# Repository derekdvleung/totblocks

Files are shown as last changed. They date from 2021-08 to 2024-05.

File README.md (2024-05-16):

# Introduction

TotBlocks are a series of 3D-printed mineral building blocks for constructing the crystal structures of biopyribole-palysepiole minerals.



[Website](https://derekdvleung.github.io/totblocks/)

[TotBlocks Video Abstract Video](https://doi.org/10.5446/57470)

[Assembly of TotBlocks Video](https://doi.org/10.5446/57471)

## How do I 3D print TotBlocks?

[3D Printing TotBlocks Video](https://doi.org/10.5446/57483)

The 3D models are available as \*.3mf (PrusaSlicer project files) and \*.stl files for 3D printing. 
Note that the \*.3mf files include the positions for support enforcers for *O* modules (`oblock`), 
whereas for \*.stl files the support enforcer (`stl/oblock/oblock-support-enforcer`) has to be added for the overhanging horizontal pegs of the *O* modules. 
When slicing (in PrusaSlicer), right click on the *O* module, then "add support enforcer".
It should be in the correct spot for single chain modules, but will need to be repositioned for other modules.
The support enforcer should be placed so that it covers the top widthwise pegs (these are overhangs, and thus need supports).

For more information on 3D printing TotBlocks, check out [TotBlocks on Printables](https://www.printables.com/model/177357-totblocks).

## Questions?

If you have any questions, start a thread in the [discussion](https://github.com/derekdvleung/totblocks/discussions)!

If you see any issues, please submit an [issue](https://github.com/derekdvleung/totblocks/issues).

# Repository contents

<!-- todo: add links -->

- [`3mf/`](3mf/)					All the \*.3mf (PrusaSlicer project files) can be found in this folder. See below (\*.stl folder contents) for descriptions of the respective \*.3mf files. Note that not all of the \*.stl files have a \*.3mf equivalent.
<!-- todo: add these files -->

- [`stl/`](stl/)					All the \*.stl files can be found in this folder.
  -	[`connectors/`](stl/connectors/)				Hexagonal pegs used to vertically connect *T*-*O*-*T* sheets for layered minerals.
	- [`brucite-connector.stl`](stl/connectors/brucite-connector.stl)			For brucite structure
	- [`chlorite-connector.stl`](stl/connectors/chlorite-connector.stl)			For chlorite structure
	- [`lizardite-connector.stl`](stl/connectors/lizardite-connector.stl)		For lizardite (kaolinite-serpentine group) structure
	- [`mica-connector.stl`](stl/connectors/mica-connector.stl)					For mica (2:1 phyllosilicate) structure
	
  - [`dual/`](stl/dual/) 							3D models used for the dual-colour version of TotBlocks (single chain, *w* = 1). 
													Each model has two parts, corresponding to two the different colours used in dual extrusion printing.
													These models should be overlain in the slicer for dual printing.
    - [`oblock-m2-plus-dual-0.stl`](stl/dual/oblock-m2-plus-dual-0.stl)			*O<sup>+</sup>* module, part 1.
    - [`oblock-m2-plus-dual-1.stl`](stl/dual/oblock-m2-plus-dual-1.stl)			*O<sup>+</sup>* module, part 2.
    - [`tblock-n1-minus-dual-0.stl`](stl/dual/oblock-n1-minus-dual-0.stl)		*T<sup>−</sup>* module, part 1.[^1]
    - [`tblock-n1-minus-dual-1.stl`](stl/dual/oblock-n1-minus-dual-1.stl)		*T<sup>−</sup>* module, part 2.[^1]
    - [`tblock-n1-plus-dual-0.stl`](stl/dual/oblock-m2-plus-dual-0.stl)			*T<sup>+</sup>* module, part 1.[^1]
    - [`tblock-n1-plus-dual-1.stl`](stl/dual/oblock-m2-plus-dual-1.stl)			*T<sup>+</sup>* module, part 2.[^1]
		
  - [`oblock/`](stl/oblock/)						*O* modules (`m` = *Z* from Nespolo and Bouznari, 2017)
    - [`oblock-m2-minus.stl`](stl/oblock/oblock-m2-minus.stl)					Single chain (*w* = 1) *O<sup>−</sup>* module.
    - [`oblock-m2-plus.stl`](stl/oblock/oblock-m2-plus.stl)						Single chain (*w* = 1) *O<sup>+</sup>* module.
    - [`oblock-m3-plus.stl`](stl/oblock/oblock-m3-plus.stl)						*Z*<sub>3</sub> *O<sup>+</sup>* module for kalifersite.
    - [`oblock-m5-minus.stl`](stl/oblock/oblock-m5-minus.stl)					Double chain (*w* = 2) *O<sup>−</sup>* module.
    - [`oblock-m5-plus.stl`](stl/oblock/oblock-m5-plus.stl)						Double chain (*w* = 2) *O<sup>+</sup>* module.
    - [`oblock-m6-plus.stl`](stl/oblock/oblock-m6-plus.stl)						*Z*<sub>6</sub> *O<sup>+</sup>* module for kalifersite.
    - [`oblock-m8-minus.stl`](stl/oblock/oblock-m8-minus.stl)					Triple chain (*w* = 3) *O<sup>−</sup>* module.
    - [`oblock-m8-plus.stl`](stl/oblock/oblock-m8-plus.stl)						Triple chain (*w* = 3) *O<sup>+</sup>* module.
    - [`oblock-m11-minus.stl`](stl/oblock/oblock-m11-minus.stl)					Quadruple chain (*w* = 4) *O<sup>−</sup>* module.
    - [`oblock-m11-plus.stl`](stl/oblock/oblock-m11-plus.stl)					Quadruple chain (*w* = 4) *O<sup>+</sup>* module.
    - [`oblock-support-enforcer.stl`](stl/oblock/oblock-support-enforcer.stl)	Support enforcer for the *O* modules. When slicing (in PrusaSlicer), right click on the *O* module, then "add support enforcer". 
																				It should be in the correct spot for single chain modules, but will need to be repositioned for other modules.
																				The support enforcer should be placed so that it covers the top widthwise pegs (these are overhangs, and thus need support).
    - [`single-octahedron-clips.stl`](stl/oblock/single-octahedron-clips.stl)	An octahedron that fits between *O* modules that are joined by phyllosilicate-type linkages to fill in the missing sites.
    - [`single-octahedron.stl`](stl/oblock/single-octahedron.stl)				An octahedron that fits between *O* modules that are joined by phyllosilicate-type linkages to fill in the missing sites.
																				This piece has additional clips that make it easier to hold on when the single octahedron is at the front or back of an *O* module.
	
  - [`quartz`](stl/quartz/)														Experimental modules for quartz. These modules do not have pags and thus have to be glued together to extend the structure.
    - [`quartz-module.stl`](stl/quartz/quartz-module.stl)						3<sub>2</sub> screw axis module for quartz (two repeats).

  - [`tblock`](stl/tblock/)							T modules (`n` = *w* from Leung and dePolo, 202x)
    - [`tblock-n1-minus.stl`](stl/tblock/tblock-n1-minus.stl)					Single chain (*w* = 1) *T<sup>−</sup>* module.[^1]
    - [`tblock-n1-plus.stl`](stl/tblock/tblock-n1-plus.stl)						Single chain (*w* = 1) *T<sup>+</sup>* module.[^1]
    - [`tblock-n2-minus.stl`](stl/tblock/tblock-n2-minus.stl)					Double chain (*w* = 2) *T<sup>−</sup>* module.[^1]
    - [`tblock-n2-plus.stl`](stl/tblock/tblock-n2-plus.stl)						Double chain (*w* = 2) *T<sup>+</sup>* module.[^1]
    - [`tblock-n3-minus.stl`](stl/tblock/tblock-n3-minus.stl)					Triple chain (*w* = 3) *T<sup>−</sup>* module.[^1]
    - [`tblock-n3-plus.stl`](stl/tblock/tblock-n3-plus.stl)						Triple chain (*w* = 3) *T<sup>+</sup>* module.[^1]
    - [`tblock-n4-minus.stl`](stl/tblock/tblock-n4-minus.stl)					Quadruple chain (*w* = 4) *T<sup>−</sup>* module.[^1] 
    - [`tblock-n4-plus.stl`](stl/tblock/tblock-n4-plus.stl)						Quadruple chain (*w* = 4) *T<sup>+</sup>* module.[^1]

- [`LICENSE`](LICENSE) 				The copyright license (GPLv3) for the TotBlocks project.
- [`totblocks.scad`](totblocks.scad)										The source code to generate TotBlocks. See below for method documentation for `totblocks.scad`.

[^1]: Note that the *T<sup>+</sup>* and *T<sup>−</sup>* notation is used here to differentiate between the two types of T modules. 
 However, the *T<sup>+</sup>* and *T<sup>−</sup>* notation actually corresponds to the orientation of the *T* modules (apices pointing up = <sup>+</sup>, down = <sup>−</sup>) rather than the modules themselves.

# Bill of materials

## Starter set (can be used to build most of the structures)

- 4× oblock-m2-plus
- 4× tblock-n1-plus
- 4× tblock-n1-minus
- 4× oblock-m5-plus
- 4× tblock-n2-plus
- 4× tblock-n2-minus
- 4× single-octahedron
- 4× single-octahedron-clips
- 2× mica-connector (or the other connectors, depending on if the others should be printed. Note: the mica connectors can be substituted for 2 cm diameter marbles or 3D-printed spheres. These represent the interlayer cations in the mica structure.)

Additional blocks beyond the starter set are needed to build the orthopyroxene, protopyroxene, [clinojimthompsonite,] chesterite, sepiolite, and kalifersite structures.

## Mica group (2:1 phyllosilicates)

- 4× oblock-m5-plus
- 4× tblock-n2-plus
- 4× tblock-n2-minus
- 2× single-octahedron
- 2× single-octahedron-clips
- 2× mica-connector (Note: the mica connectors can be substituted for 2 cm diameter marbles or 3D-printed spheres. These represent the interlayer cations in the mica structure.)

[2:1 Phyllosilicates Video](https://doi.org/10.5446/57470)

## Pyroxene group

[Pyroxene Group Video](https://doi.org/10.5446/57473)

### Clinopyroxene

- 4× oblock-m2-plus
- 4× tblock-n1-plus
- 4× tblock-n1-minus

[Pyroxene Group Video](https://doi.org/10.5446/57473)

### Orthopyroxene

- 4× oblock-m5-plus
- 4× oblock-m5-minus
- 8× tblock-n2-plus
- 8× tblock-n2-minus

[Pyroxene Group Video](https://doi.org/10.5446/57473)

### Protopyroxene

- 4× oblock-m5-plus
- 4× oblock-m5-minus
- 8× tblock-n2-plus
- 8× tblock-n2-minus

[Pyroxene Group Video](https://doi.org/10.5446/57473)

## Amphibole supergroup

- 4× oblock-m5-plus
- 4× tblock-n2-plus
- 4× tblock-n2-minus

[Amphibole Supergroup Video](https://doi.org/10.5446/57474)

## Clinojimthompsonite

- 4× oblock-m8-plus
- 4× tblock-n3-plus
- 4× tblock-n3-minus

[Clinojimthompsonite and Chesterite Video](https://doi.org/10.5446/57475)

## Chesterite

- 2× oblock-m5-plus
- 2× oblock-m5-minus
- 4× tblock-n2-plus
- 4× tblock-n2-minus
- 2× oblock-m8-plus
- 2× oblock-m8-minus
- 4× tblock-n3-plus
- 4× tblock-n3-minus

[Clinojimthompsonite and Chesterite Video](https://doi.org/10.5446/57475)

## Palygorskite group

- 4× oblock-m5-plus
- 4× tblock-n2-plus
- 4× tblock-n2-minus

[Palygorskite Group](https://doi.org/10.5446/57476)

## Sepiolite group

- 2× oblock-m8-plus
- 2× oblock-m8-minus
- 4× tblock-n3-plus
- 4× tblock-n3-minus

[Sepiolite Group](https://doi.org/10.5446/57477)

## Kalifersite

- 4× oblock-m3-plus
- 4× tblock-n2-plus
- 4× tblock-n2-minus
- 4× oblock-m6-plus
- 4× tblock-n3-plus
- 4× tblock-n3-minus

[Kalifersite Video](https://doi.org/10.5446/57479)

## Brucite group

- 4× oblock-m5-plus
- 2× single-octahedron
- 2× single-octahedron-clips
- 4× brucite-connector

[Brucite Group Video](https://doi.org/10.5446/57480)

## Lizardite (kaolinite-serpentine group)

- 4× oblock-m5-plus
- 4× tblock-n2-plus
- 2× single-octahedron
- 2× single-octahedron-clips
- 4× lizardite-connector

[Kaolinite-Serpentine Group Video](https://doi.org/10.5446/57481)

## Chlorite group

- 4× oblock-m5-plus
- 2× oblock-m5-minus
- 4× tblock-n2-plus
- 4× tblock-n2-minus
- 3× single-octahedron
- 3× single-octahedron-clips
- 4× chlorite-connector

[Chlorite Group](https://doi.org/10.5446/57482)

# Method documentation

## Hard-coded parameters
<!-- todo: flush this out -->
These parameters are hard-coded into the TotBlocks file, but they can be adjusted using the built-in Customizer in OpenSCAD.

### Module size parameters
`t` = the true side length of the tetrahedra in the *T* modules (default 10 mm). This will define the size of both the *T* and *O* modules, since both are geometrically related.  
`numBlocks` = periodic length of the blocks (*l* in Leung and dePolo, 202x). Note that the code currently does not support half lengths.

### Peg size parameters
`pegRadius` = radius of the horizontal and vertical pegs (default 1.8 mm).  
`pegZLength` = length of vertical pegs (Z direction) (default 2.4 mm).  
`pegYLength` = length of lengthwise pegs (Y direction) (default 5 mm).  
`pegXLength` = length of widthwise pegs (X direction) (default 5 mm).  
`pegZLowerLength` = length that the vertical pegs (Z direction) should extend (default 4.4 mm).  
`pegZRotate` = orientation of the vertical pegs (Z direction) (default 90 degrees).  
`oAdjustHexHeight` = height of the hexagonal slots (Z direction) in the O modules (default 2.6 mm).  
`tMinusCutoff` = Offset used to determine where the widthwise side of the *T* modules are cut off (default 0 mm).  
`tetBridgeHeight` = Offset used for the height of the rectangular bridges that connect the tetrahedra in the *T* modules (default 0 mm).  

### Tolerance parameters
`toleranceZ` = tolerance for the radius of the vertical pegs (Z direction) (default 0 mm).  
`tZMinusTolerance` = (deprecated) tolerance for slots in *T<sup>−</sup>* modules (slots were replaced by pegs in a newer iteration) (default 0 mm).  
`lengthTolerance` = tolerance for lengths of vertical pegs (Z direction) (default 0.2 mm).  
`SlotXHeightTolerance` = extends the height (Z direction) for the widthwise pegs (X direction) to reduce issues from sagging due to bridging (default 0.6 mm).  
`toleranceXY` = tolerance for the radius of the lengthwise and widthwise pegs (Y and X directions, respectively) (default 0 mm).  

## Constants
These values are used for internal reference (don't change them).  
`PLUS = 1` constant used to denote positive orientation.  
`MINUS = 0` constant used to denote negative orientation.  

`T_SINGLE_CHAIN = 1` constant for single-chain-width *T* modules.  
`T_DOUBLE_CHAIN = 2` constant for double-chain-width *T* modules.  
`T_TRIPLE_CHAIN = 3` constant for triple-chain-width *T* modules.  

`O_SINGLE_CHAIN = 2` constant for single-chain-width *O* modules.  
`O_DOUBLE_CHAIN = 5` constant for double-chain-width *O* modules.  
`O_TRIPLE_CHAIN = 8` constant for triple-chain-width *O* modules.  

## TotBlocks modules

	tBlock (n = 1, apex = PLUS);

Produces a *T* module of certain width and polarity.

`n` = width of module (`T_SINGLE_CHAIN` = 1, `T_DOUBLE_CHAIN` = 2, `T_TRIPLE_CHAIN` = 3)  
`apex` = direction that the tetrahedra point (`PLUS` or `MINUS`)[^1]

***

	oBlock (m = 2, apex = PLUS);

Produces an *O* module of certain width and polarity

`m` = number of *M* sites in the module (`O_SINGLE_CHAIN` = 2, `O_DOUBLE_CHAIN` = 5, `O_TRIPLE_CHAIN` = 8)  
`apex` = direction that the octahedra point (`PLUS` or `MINUS`)

***

	oBlockKalifersite (m = 3, apex = PLUS);

A temporary method for producing O modules for kalifersite, which have the width-wise pegs removed. It is anticipated that this method will be deprecated and added to the `oBlock` method.
 
`m` = number of *M* sites in the module (3 = *Z*<sub>3</sub> module (double chain), 6 = *Z*<sub>6</sub> module (triple chain))  
`apex` = direction that the octahedra point (`PLUS` or `MINUS`)

## Single octahedron pieces

	oBlockOne (apex = PLUS, pegs = true);

Produces a single octahedron piece. Note that there is no difference between PLUS and MINUS versions.

`apex` = direction that the octahedra point (`PLUS` or `MINUS`)  
`pegs` = if `TRUE`, includes clips for the octahedra; if `FALSE`, does not include clips

## Peg connectors

	micaPeg ();

Produces a vertical peg for the mica-group minerals.

***

	chloriteBrucitePeg (length);

Produces a vertical peg for the chlorite and brucite groups, as well as lizardite (kaolinite-serpentine group)

`length` = length of peg (chlorite = `CHLORITE_HEIGHT`, brucite = `BRUCITE_HEIGHT`, lizardite = `LIZARDITE_HEIGHT`)

## Dual prints

	oBlockDual (apex = PLUS, dual = 0);

Produces two parts of a dual print for single-chain-width *O* modules.

`apex` = direction that the octahedra point (`PLUS` or `MINUS`)  
`dual` = part number (`0` or `1`)

***

	tBlockDual2 (n = 1, apex = PLUS, dual = 0);

Produces two parts of a dual print for *T* modules.

`n` = width of module (`1` = single chain, `2` = double chain, `3` = triple chain)  
`apex` = direction that the tetrahedra point (`PLUS` or `MINUS`)[^1]  
`dual` = part number (`0` or `1`)  

## Quartz

	quartzModule ();

Produces a quartz module.

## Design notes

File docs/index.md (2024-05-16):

Table of contents
* TOC
{:toc}

<!-- This is a test landing page for TotBlocks. -->

<!-- TODO: add paper link, youtube resources, printables -->

# Introduction

<iframe width="560" height="315" src="https://www.youtube.com/embed/pNsD5MDUdqU" title="YouTube video player" frameborder="0" allow="accelerometer; autoplay; clipboard-write; encrypted-media; gyroscope; picture-in-picture; web-share" allowfullscreen></iframe>

TotBlocks are a series of 3D-printed mineral building blocks for constructing the crystal structures of modular rock-forming minerals, including minerals of the biotite-pyroxene-amphibole (biopyribole) and palygorskite-sepiolite (palysepiole) series, as well as layered minerals of the brucite, kaolinite-serpentine, and chlorite groups. To learn more about TotBlocks, check out the video above and the papers on the design and theory of TotBlocks, as well as a case study of using TotBlocks in an undergradute mineralogy lab session.

## Useful publications and links

- **TotBlocks design and theory paper:** [Leung, D.D.V. and dePolo, P.E. (2022) TotBlocks: exploring the relationships between modular rock-forming minerals with 3D-printed interlocking brick modules. _European Journal of Mineralogy_, 34, 523-538, https://doi.org/10.5194/ejm-34-523-2022.](https://ejm.copernicus.org/articles/34/523/2022/)

- **TotBlocks pedagogical case study:** [Leung, D.D.V. and dePolo, P.E. (2023) GC Insights: The crystal structures behind the optical properties of minerals - a case study of using TotBlocks in an undergraduate mineralogy lab. _Geoscience Communcation_, preprint on EGUsphere, https://doi.org/10.5194/egusphere-2023-294.](https://egusphere.copernicus.org/preprints/2023/egusphere-2023-294/)

- **TotBlocks mirrored repository on Zenodo:** [Leung, D.D.V. (2022) derekdvleung/totblocks: TotBlocks 2022.05 (totblocks-2022.05), Zenodo [code], https://doi.org/10.5281/zenodo.5240816.](https://zenodo.org/badge/latestdoi/398404495) 
<!-- [![DOI](https://zenodo.org/badge/398404495.svg)](https://zenodo.org/badge/latestdoi/398404495)-->

- **TotBlocks YouTube playlist:** [https://youtube.com/playlist?list=PLn1WI6cV9CAvNvtO0wXdM_Uy9zV6C942s](https://youtube.com/playlist?list=PLn1WI6cV9CAvNvtO0wXdM_Uy9zV6C942s)

- **TotBlocks on GitHub:** [https://github.com/derekdvleung/totblocks](https://github.com/derekdvleung/totblocks)
  -	If you have any questions, please start a thread in the [discussion here](https://github.com/derekdvleung/totblocks/discussions).
If you see any issues, please submit an [issue here](https://github.com/derekdvleung/totblocks/issues).

# How do I 3D print TotBlocks?

<iframe width="560" height="315" src="https://www.youtube.com/embed/GAaxp7R7IAs" title="YouTube video player" frameborder="0" allow="accelerometer; autoplay; clipboard-write; encrypted-media; gyroscope; picture-in-picture; web-share" allowfullscreen></iframe>

To 3D print TotBlocks, check out the video above. The 3D models for TotBlocks can be found on [Printables here](https://www.printables.com/model/177357-totblocks). The 3D models are available as \*.3mf (PrusaSlicer project files) and \*.stl files for 3D printing. 
Note that the \*.3mf files include the positions for support enforcers for *O* modules (`oblock`) to be used with PrusaSlicer, 
whereas for \*.stl files the support enforcer (`stl/oblock/oblock-support-enforcer`) has to be added for the overhanging horizontal pegs of the *O* modules. 
When slicing (in PrusaSlicer), right click on the *O* module, then "add support enforcer".
It should be in the correct spot for single chain modules, but will need to be repositioned for other modules.
The support enforcer should be placed so that it covers the top widthwise pegs (these are overhangs, and thus need supports).

## Supported 3D printers

TotBlocks has been tested on the following 3D printers:
- Prusa i3 MK3S (original design for TotBlocks)
- Creality Ender 5 (Laurentian University)
- Creality Ender 3 (thanks to Phillip Barak for testing) 
- Ultimaker S5 (some issues with peg and slot tolerances)
- MakerBot Sketch Large (thanks to Loretta Dickson for testing)
- Entina (thanks to Loretta Dickson for testing)

# Building the crystal structures

<iframe width="560" height="315" src="https://www.youtube.com/embed/JqNwlT4ukXY" title="YouTube video player" frameborder="0" allow="accelerometer; autoplay; clipboard-write; encrypted-media; gyroscope; picture-in-picture; web-share" allowfullscreen></iframe>

## Mica group (2:1 phyllosilicates)

<iframe width="560" height="315" src="https://www.youtube.com/embed/B0o2lecr-tU" title="YouTube video player" frameborder="0" allow="accelerometer; autoplay; clipboard-write; encrypted-media; gyroscope; picture-in-picture; web-share" allowfullscreen></iframe>

Watch the video above to learn more about the 2:1 phyllosilicates, and construct the crystal structure of the mica group using TotBlocks.

Parts needed:
- 4× oblock-m5-plus
- 4× tblock-n2-plus
- 4× tblock-n2-minus
- 2× single-octahedron
- 2× single-octahedron-clips
- 2× mica-connector (Note: the mica connectors can be substituted for 2 cm diameter marbles or 3D-printed spheres. These represent the interlayer cations in the mica structure.)

## Pyroxene group

<iframe width="560" height="315" src="https://www.youtube.com/embed/7puU0kn26aU" title="YouTube video player" frameborder="0" allow="accelerometer; autoplay; clipboard-write; encrypted-media; gyroscope; picture-in-picture; web-share" allowfullscreen></iframe>

Watch the video above to learn more about the pyroxenes and their three structural varieties ('polytypes')

### Clinopyroxene

Parts needed:
- 4× oblock-m2-plus
- 4× tblock-n1-plus
- 4× tblock-n1-minus

### Orthopyroxene

Parts needed:
- 4× oblock-m5-plus
- 4× oblock-m5-minus
- 8× tblock-n2-plus
- 8× tblock-n2-minus

### Protopyroxene

Parts needed:
- 4× oblock-m5-plus
- 4× oblock-m5-minus
- 8× tblock-n2-plus
- 8× tblock-n2-minus

## Amphibole supergroup

<iframe width="560" height="315" src="https://www.youtube.com/embed/ZTIgtaDmqug" title="YouTube video player" frameborder="0" allow="accelerometer; autoplay; clipboard-write; encrypted-media; gyroscope; picture-in-picture; web-share" allowfullscreen></iframe>

Parts needed:
- 4× oblock-m5-plus
- 4× tblock-n2-plus
- 4× tblock-n2-minus

## Clinojimthompsonite

<iframe width="560" height="315" src="https://www.youtube.com/embed/aJ-CMEkaL5I" title="YouTube video player" frameborder="0" allow="accelerometer; autoplay; clipboard-write; encrypted-media; gyroscope; picture-in-picture; web-share" allowfullscreen></iframe>

Parts needed:
- 4× oblock-m8-plus
- 4× tblock-n3-plus
- 4× tblock-n3-minus

## Chesterite

<iframe width="560" height="315" src="https://www.youtube.com/embed/aJ-CMEkaL5I" title="YouTube video player" frameborder="0" allow="accelerometer; autoplay; clipboard-write; encrypted-media; gyroscope; picture-in-picture; web-share" allowfullscreen></iframe>

Parts needed:
- 2× oblock-m5-plus
- 2× oblock-m5-minus
- 4× tblock-n2-plus
- 4× tblock-n2-minus
- 2× oblock-m8-plus
- 2× oblock-m8-minus
- 4× tblock-n3-plus
- 4× tblock-n3-minus

## Palygorskite group

<iframe width="560" height="315" src="https://www.youtube.com/embed/_oIfYW3Yn7k" title="YouTube video player" frameborder="0" allow="accelerometer; autoplay; clipboard-write; encrypted-media; gyroscope; picture-in-picture; web-share" allowfullscreen></iframe>

Parts needed:
- 4× oblock-m5-plus
- 4× tblock-n2-plus
- 4× tblock-n2-minus

## Sepiolite group

<iframe width="560" height="315" src="https://www.youtube.com/embed/Y6VKkh_y93w" title="YouTube video player" frameborder="0" allow="accelerometer; autoplay; clipboard-write; encrypted-media; gyroscope; picture-in-picture; web-share" allowfullscreen></iframe>

Parts needed:
- 2× oblock-m8-plus
- 2× oblock-m8-minus
- 4× tblock-n3-plus
- 4× tblock-n3-minus

## Kalifersite

<iframe width="560" height="315" src="https://www.youtube.com/embed/xG3E6Dk2YI0" title="YouTube video player" frameborder="0" allow="accelerometer; autoplay; clipboard-write; encrypted-media; gyroscope; picture-in-picture; web-share" allowfullscreen></iframe>

Parts needed:
- 4× oblock-m3-plus
- 4× tblock-n2-plus
- 4× tblock-n2-minus
- 4× oblock-m6-plus
- 4× tblock-n3-plus
- 4× tblock-n3-minus

## Brucite group

<iframe width="560" height="315" src="https://www.youtube.com/embed/X81bQ844Kgs" title="YouTube video player" frameborder="0" allow="accelerometer; autoplay; clipboard-write; encrypted-media; gyroscope; picture-in-picture; web-share" allowfullscreen></iframe>

Parts needed:
- 4× oblock-m5-plus
- 2× single-octahedron
- 2× single-octahedron-clips
- 4× brucite-connector

## Lizardite (kaolinite-serpentine group)

<iframe width="560" height="315" src="https://www.youtube.com/embed/_taepX3pt5U" title="YouTube video player" frameborder="0" allow="accelerometer; autoplay; clipboard-write; encrypted-media; gyroscope; picture-in-picture; web-share" allowfullscreen></iframe>

Parts needed:
- 4× oblock-m5-plus
- 4× tblock-n2-plus
- 2× single-octahedron
- 2× single-octahedron-clips
- 4× lizardite-connector

## Chlorite group

<iframe width="560" height="315" src="https://www.youtube.com/embed/0-9Vbss5MxI" title="YouTube video player" frameborder="0" allow="accelerometer; autoplay; clipboard-write; encrypted-media; gyroscope; picture-in-picture; web-share" allowfullscreen></iframe>

Parts needed:
- 4× oblock-m5-plus
- 2× oblock-m5-minus
- 4× tblock-n2-plus
- 4× tblock-n2-minus
- 3× single-octahedron
- 3× single-octahedron-clips
- 4× chlorite-connector

# Contact

To contact Derek D.V. Leung, check out [the contact form on his website here](https://derekdvleung.wixsite.com/main/contact).

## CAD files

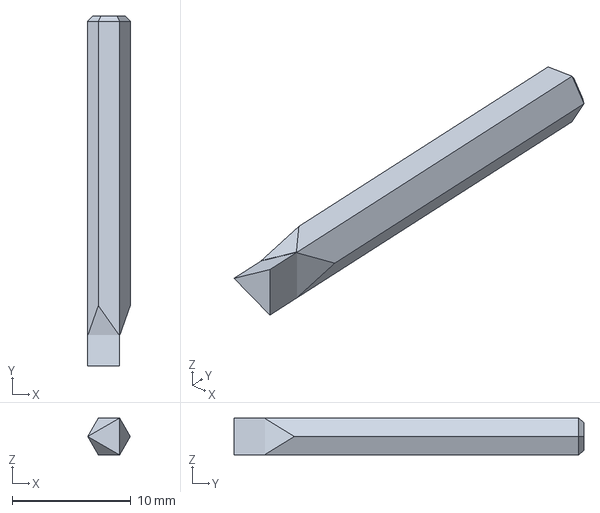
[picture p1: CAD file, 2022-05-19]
3mf/connectors/lizardite-connector.3mf
3.60 x 29.5 x 3.12 mm

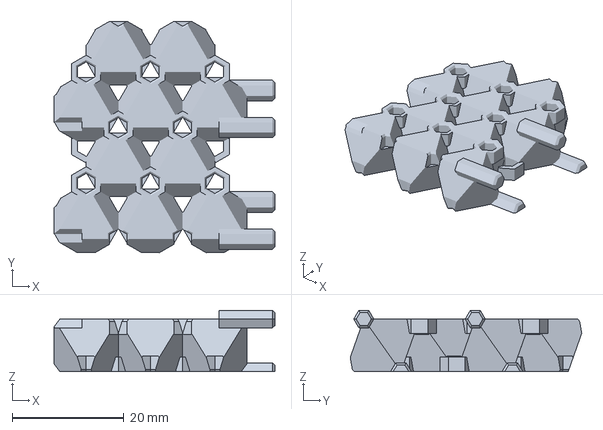
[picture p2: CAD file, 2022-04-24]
3mf/oblock/oblock-m5-minus.3mf
39.6 x 41.5 x 11.0 mm

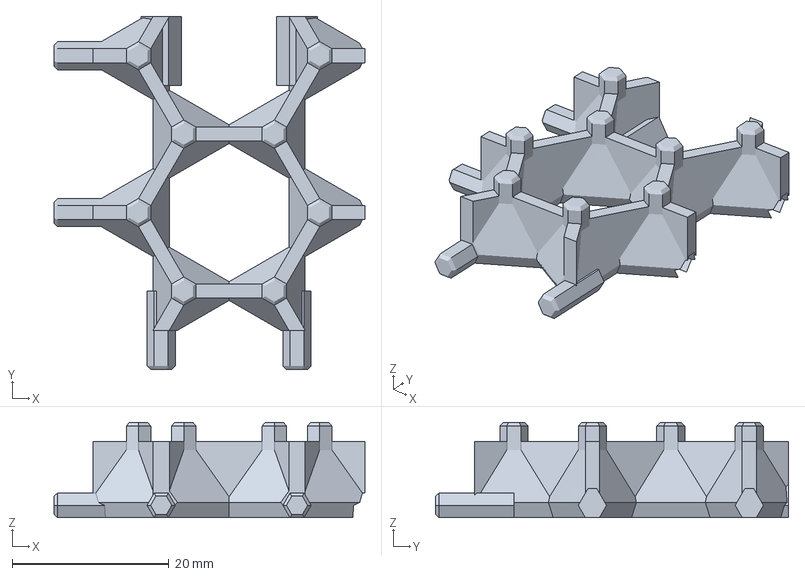
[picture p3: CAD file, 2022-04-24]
3mf/tblock/tblock-n2-minus.3mf
39.6 x 45.0 x 12.1 mm

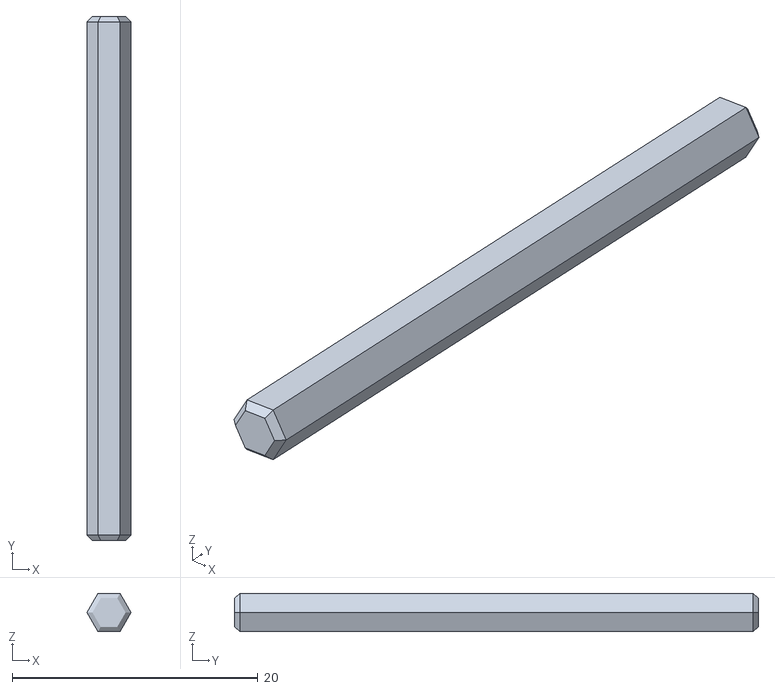
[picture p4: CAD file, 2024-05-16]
stl/connectors/smectite-connector.stl
3.60 x 42.6 x 3.12

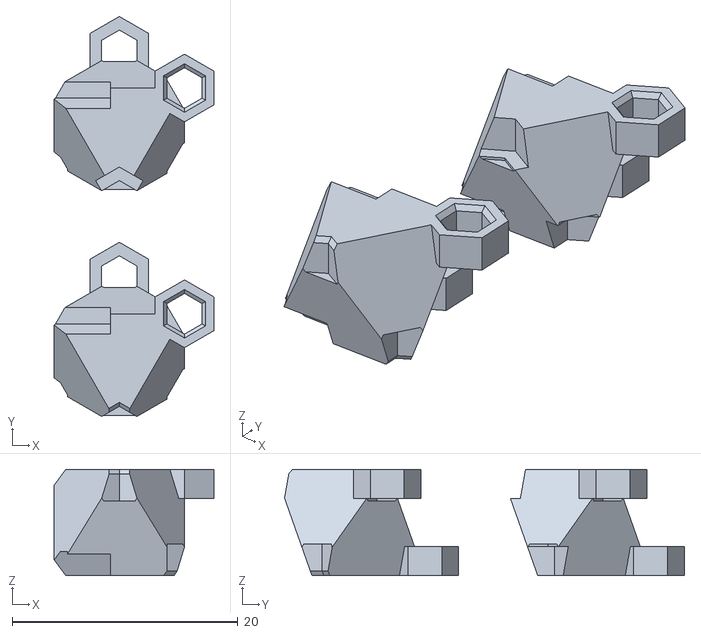
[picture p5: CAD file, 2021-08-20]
stl/dual/oblock-m2-plus-dual-0.stl
14.1 x 35.4 x 9.43

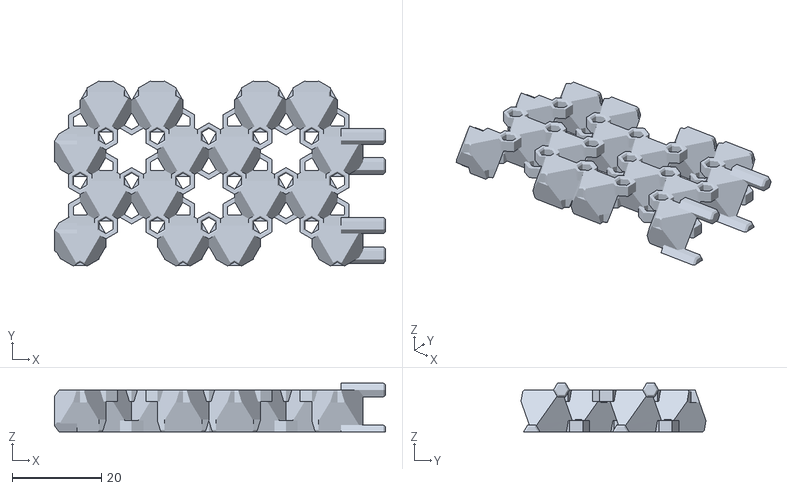
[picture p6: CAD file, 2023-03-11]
stl/oblock/dioctahedral/oblock-dioctahedral-m11-plus.stl
74.3 x 41.5 x 11.0

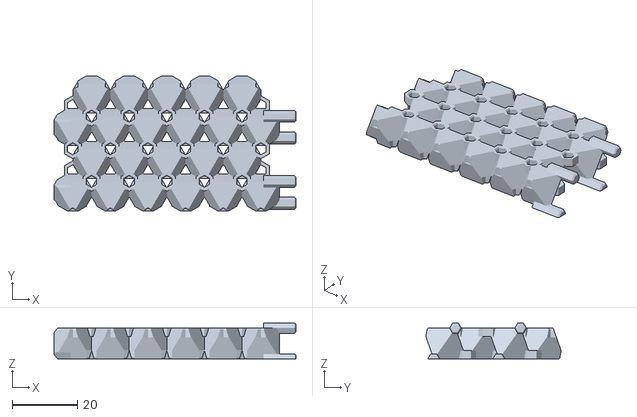
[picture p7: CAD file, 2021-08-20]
stl/oblock/oblock-m11-plus.stl
74.3 x 41.5 x 11.0

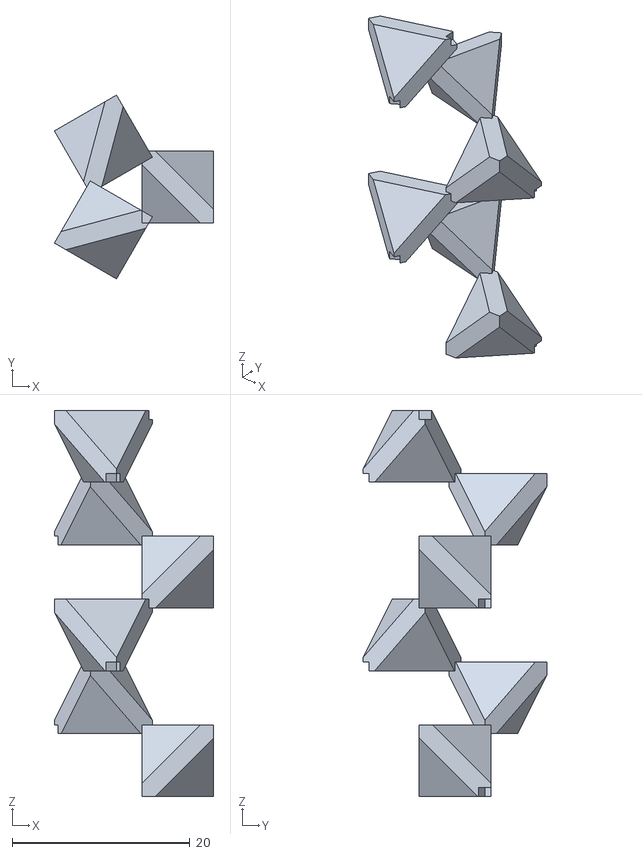
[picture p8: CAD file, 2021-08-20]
stl/quartz/quartz-module.stl
17.9 x 20.7 x 43.4

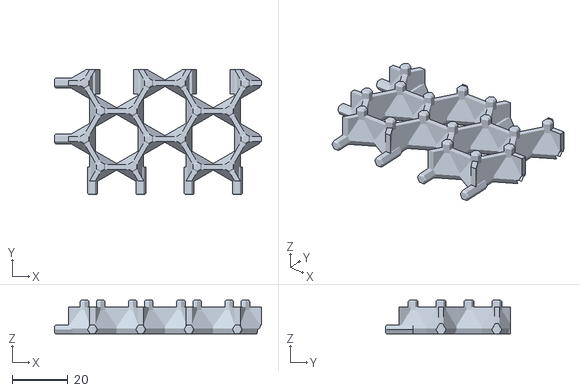
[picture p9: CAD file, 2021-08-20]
stl/tblock/tblock-n4-minus.stl
74.3 x 45.0 x 12.1

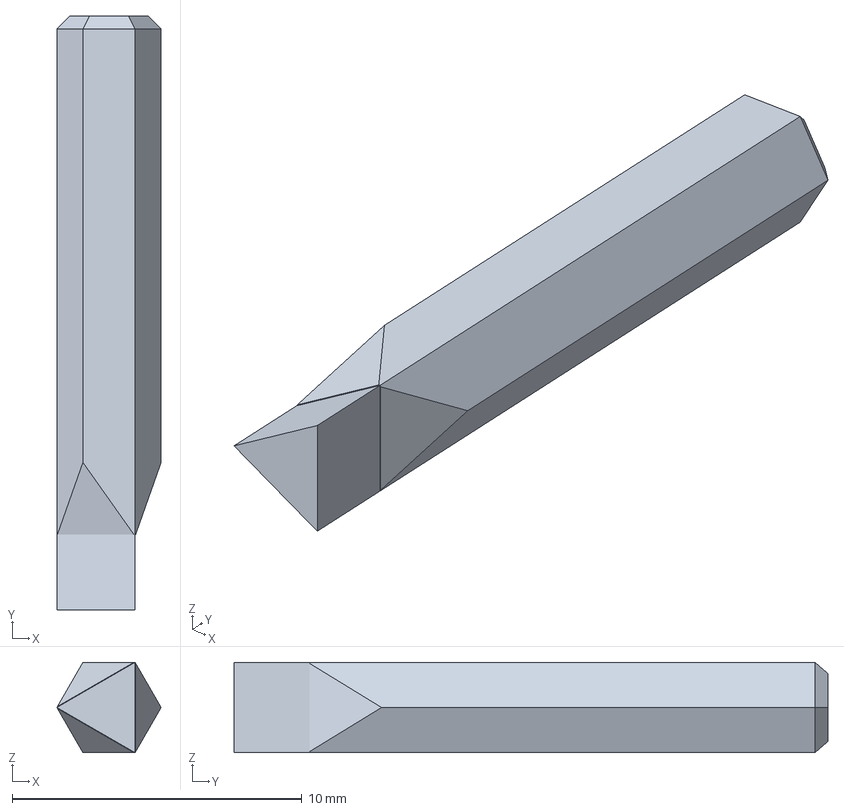
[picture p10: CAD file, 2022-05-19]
3mf/connectors/brucite-connector.3mf
3.60 x 20.5 x 3.12 mm

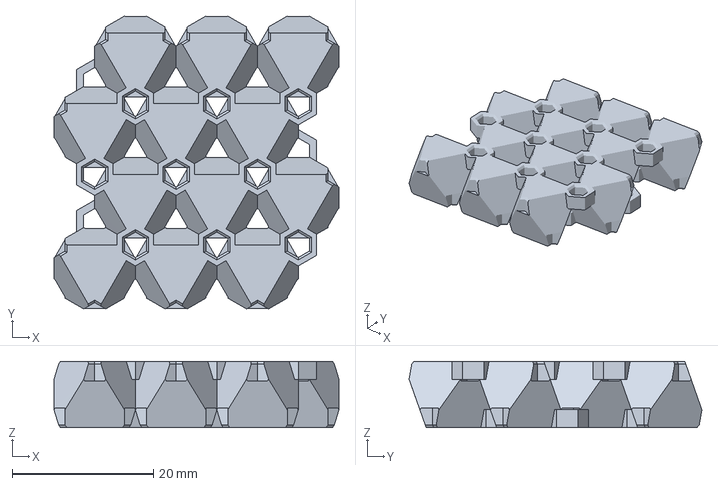
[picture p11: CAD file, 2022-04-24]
3mf/oblock/oblock-m6-plus.3mf
40.4 x 41.5 x 9.43 mm

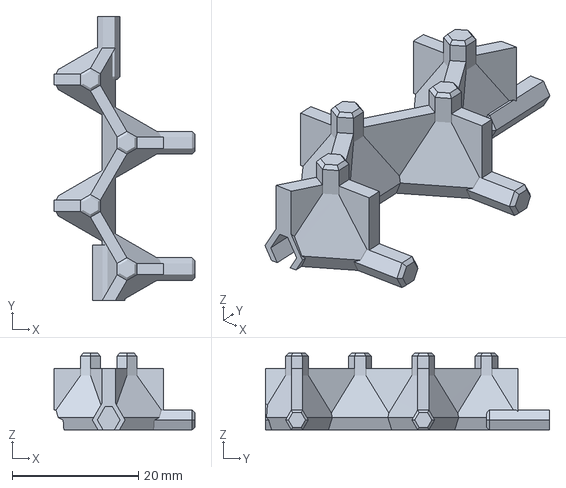
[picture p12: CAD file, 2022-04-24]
3mf/tblock/tblock-n1-plus.3mf
22.3 x 45.0 x 12.1 mm

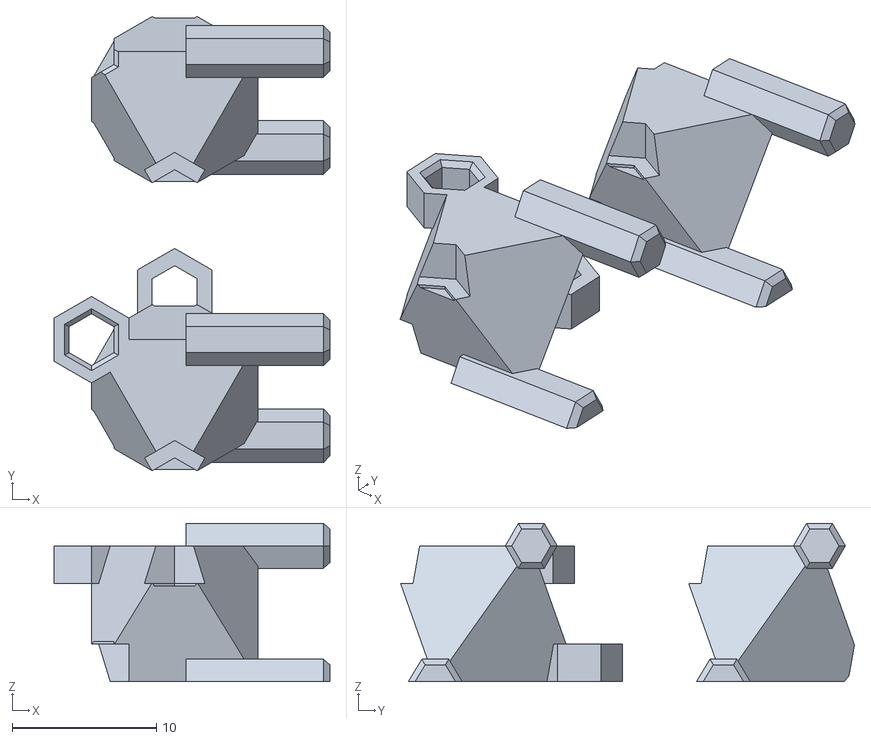
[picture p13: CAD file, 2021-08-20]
stl/dual/oblock-m2-plus-dual-1.stl
19.1 x 31.5 x 11.0

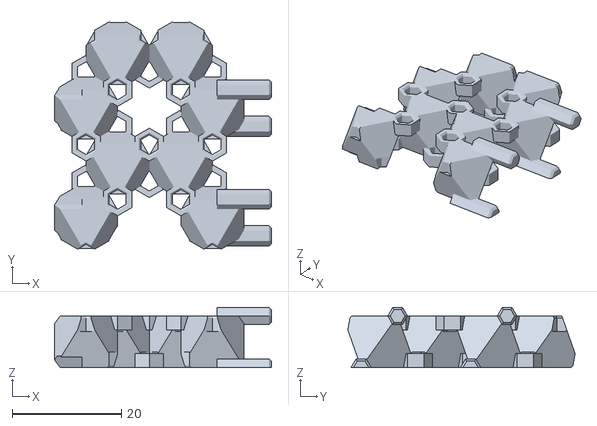
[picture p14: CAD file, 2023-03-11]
stl/oblock/dioctahedral/oblock-dioctahedral-m5-plus.stl
39.6 x 41.5 x 11.0

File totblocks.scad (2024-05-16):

/* Copyright (C) 2021 Derek Leung <dleung@laurentian.ca>
    This program is free software: you can redistribute it and/or modify it under the terms of the GNU General Public License version 3 as published by the Free Software Foundation. This program is distributed in the hope that it will be useful, but WITHOUT ANY WARRANTY; without even the implied warranty of MERCHANTABILITY or FITNESS FOR A PARTICULAR PURPOSE.  See the GNU General Public License for more details. You should have received a copy of the GNU General Public License along with this program.  If not, see <https://www.gnu.org/licenses/>.
*/

/*TODO:
-put peg holes into T modules so that M2, M4, A, and I sites can be inserted into the structure
-convert modules to include variable length parameters
-convert O module so that half lengths are possible*/

/*********************************************************************************************************

                            PARAMETERS

**********************************************************************************************************/

/* [Module size parameters] */
//Length of the blocks (l) N.B. currently does not support half lengths
numBlocks = 2; 
// Tetrahedron side length (mm)
t = 10;//10;  // tetrahedron side length
a = t/2; // tetrahedron half side length
ts = sqrt(3)/2*t; // slant height of tetrahedron
tx = t/sqrt(12); //length of line segment from base of triangle to centroid of triangle
th = sqrt(6)/3*t; // true height of tetrahedron
tCR = sqrt(6)/4*t; //circumradius of tetrahedron

factor = tCR/1.62; //the scale of the structure, assuming a Si-O bond distance of 1.62 A (Smith and Bailey, 1963)

//echo(oh);
echo ("factor:" , factor);
echo (factor*3.2/2);
echo (tCR);
echo (th/factor); // real height of tetrahedron in A
echo (oh/factor); // real height of octahedron in A

o = 2*(ts-tx);
b = o/2;
os = sqrt(3)/2*o; // slant height of octahedron face
ox = os/3;
oa = 4*ox; //apex-to-apex length of octahedron (flat)
oh = sqrt(o*o-(2*ox*2*ox)); //true height of flat-lying octahedron
oCR = o*sqrt(1/2); // double-checked bond distance of O sites

//These minerals use vertical pegs to connect the O-O underside bonds, i.e., chloriteBrucitePeg module
MICA_HEIGHT = 3.2*factor + 2*th; // based on Hendricks and Jefferson (1939)
CHLORITE_HEIGHT = 7.01*factor; // based on Zanazzi et al. (2007)
BRUCITE_HEIGHT = 4.73*factor; // based on Nagai et al. (2000)
LIZARDITE_HEIGHT =7.23*factor; // based on Mellini (1982)
SMECTITE_HEIGHT = 15*factor - oh; // this is the true vertical distance based on Viani et al (2002)
                //12.98*factor; // this value is the slant height of the pegs, including offset, based on Viani et al. (2002)


echo (oCR/factor); // bond distance of O sites

echo (2*ts/(oh+2*th)); // ratio of width to height of modules

echo ((th+oh)/(oh+2*th)); // vertical offset for pyribole-type linkages

/* [Peg size parameters] */
//Radius of the horizontal (lengthwise and widthwise) and vertical pegs
pegRadius = 1.8;//1; 

//Length of vertical pegs
pegZLength = 2.4;////oh/2; 

//Length of lengthwise pegs
pegYLength = 5;//b;//b; 

//Length of widthwise pegs
pegXLength = 5;//b;

//Extends the opposite end of the vertical pegs on the Z axis (mm)
pegZLowerLength = 4.4;//2.4;// 4.4; 

//Orientation of the vertical pegs
pegZRotate =90;//0

//Determines the height of the hexagonal slots in the O modules
oAdjustHexHeight =2.6;//oh/2-pegZLength ;// 2.2;

//Offset used to determine where the widthwise side of the T modules are cut off
tMinusCutoff = 0;

//Offset for the height of the rectangular bridges that connect the tetrahedra in the T modules
tetBridgeHeight = 0;//2.66-0.8; //2.66 to get flush edges




extraBlocks = numBlocks-1; //number of blocks, not including base block

/* [Tolerance parameters] */

echo(b);
//Tolerance for Z peg radius
toleranceZ = 0; 

//Tolerance for Z peg length
lengthTolerance =0.2; 

//Extends widthwise and lengthwise slots for a specified Z height to reduce sagging from bridging
slotXHeightTolerance =0.6;

// Vertical offset used for adding thickness to pegs
toleranceXY = 0;
tOffset = sqrt(3)/2*pegRadius; 
//tExpand = 0;//5;//3;
//tExpandHeight = 0;//th+tOffset;

/* [Deprecated] */
// Colors for simpTOT module, that shows idealized T and O modules - only works in Preview Mode
tColor = "crimson";
oColor = "yellowgreen";
oMColor = "yellow";

bottomDesignHeight = 0.4;

tZMinusTolerance = 0;

//Increases the size of the tetrahedra in the T modules of a previous iteration of TotBlocks
tBaseScale = 1;//1.4; //1.2


// This module prevents internal constants from being customized.
module customizerLimit (){}

// CONSTANTS
PLUS = 0; // constants used to define the direction of the modules
MINUS = 1; // constants used to define the direction of the modules

// Variable note:
// n = number of tetrahedra per basic module (T/2)
// n = 1,2,3...
// m = number of octahedra per basic module (Z)
// m = 2,5,8...
// m = 3n-1

T_SINGLE_CHAIN = 1; // single chain, n=1
T_DOUBLE_CHAIN = 2; // double chain, n=2
T_TRIPLE_CHAIN = 3; // triple chain, n=3
O_SINGLE_CHAIN = 2; // single chain, m =2
O_DOUBLE_CHAIN = 5; // double chain, m = 5
O_TRIPLE_CHAIN = 8; // double chain, m=4



/*********************************************************************************************************

									GEOMETRY AND POLYHEDRA

**********************************************************************************************************/

module tet(){
points = [[-1/sqrt(3)*a,a,0], [-1/sqrt(3)*a,-a,0], [2/sqrt(3)*a,0,0], [0,0,4/sqrt(6)*a]];
polyhedron(points, [[2,0,1], [1,0,3], [2,1,3], [3,0,2]]);
}

module tetBase(){
points = 
	[[-1/sqrt(3)*a,a,0], 
	[-1/sqrt(3)*a,-a,0], 
	[2/sqrt(3)*a,0,0], 
	[-1/sqrt(3)*a,a,-tOffset], 
	[-1/sqrt(3)*a,-a,-tOffset], 
	[2/sqrt(3)*a,0,-tOffset]];
polyhedron(points, [[0,2,1], [3,4,5],[0,1,4,3],[1,2,5,4],[2,0,3,5]]);//[0,1,4,3],[1,2,5,4],[2,0,3,5]]);
	//[[2,0,1], [4,3,5], [1,0,3,4],[2,1,4,5],[0,2,5,3]]);
}

module triPrism(radius, height){
points = 
	[[-sqrt(3)/2*radius,3/2*radius,0], 
	[-sqrt(3)/2*radius,-3/2*radius,0], 
	[sqrt(3)*radius,0,0], 
	[-sqrt(3)/2*radius,3/2*radius,height], 
	[-sqrt(3)/2*radius,-3/2*radius,height], 
	[sqrt(3)*radius,0,height]];
polyhedron(points, [[2,0,1], [4,3,5], [1,0,3,4],[2,1,4,5],[0,2,5,3]]);
}

module 2tet(){
translate([-(ts-tx),0,0])
tet();   
translate([-(ts+tx),t,0])
mirror([1,0,0])
tet();
}

module tetT(n=1){
		for (i = [1:n]){
		//mirror([1,0,0])
		translate([2*ts*(i-(i+1)%2-1),0,0])
		//if (i%2==0) // if even
		mirror([(i+1)%2,0,0])
		2tet();
	}
}

module tModule (n=1){
	slideY(2*t, extraBlocks)
		tetT(n);
}

// slides an object a distance on the x-axis and repeats the transformation a given number of times
module slideY(distance, repeats){
    for (i=[0:repeats]){
		translate([0,distance*i,0])
		children();
    }
}

// makes a flat-lying octahedron
module oct(){
    points = [
        [b,  ox,        oh],
        [0,  -(os-ox),  oh],
        [-b, ox,        oh],
        [b,  -ox,        0],
        [0,  (os-ox),  0],
        [-b, -ox,        0]];

    polyhedron(points, 
        [[2,0,1], 
        [4,0,2],
        [1,0,3],
        [3,0,4],
        [1,5,2],
        [5,1,3],
        [2,5,4],
        [3,4,5]]);
}

module mirrorX(){
    mirror([1,0,0])
    children();
    children();
}

module 5o(){
    mirrorX()
    3o();
}

module 3o(){

    translate([b,os,0])
    oct();
    translate([o,0,0])
    oct();
    oct();
}

module 2oct(){

    translate([-b,os,0])
    oct();
    translate([-o,0,0])
    oct();
}

// makes one unit of O module. 
// m = number of octahedra in one unit (i.e., Z)
// apex = direction of polyhedral apex (0 = up, 1 = down)
module octZ(m=2, apex = PLUS, oddsEvens = 0){
	translate([-o,0,0]){
	if(oddsEvens==0||oddsEvens==1){//odd
		for (i=[1:2:m]){
			translate([b*(i-1),0,0])
			mirror([0,apex,0])
			oct();
		}
	}
	if(oddsEvens ==0||oddsEvens ==2){
		for (i=[2:2:m]){
			translate([b*(i-1),os,0])
			mirror([0,apex,0])
			oct();
		}
	}
	}
}

module octZ2(z =2,  apex = PLUS){
	translate([-o,0,0]){
		if (z%2==1){
				translate([b*(z-1),0,0])
				mirror([0,apex,0])
				children();
		}
		if (z%2==0){
				translate([b*(z-1),os,0])
				mirror([0,apex,0])
				children();
		}
	}
}

//moves an object to a specified octahedron
module octZ3(column = 2, row = 1,  apex = PLUS){
	translate([-o,0,0]){
			translate([b*(column-1)*2+(row%2==0?b:0),(row-1)*t,0])
			mirror([0,apex,0])
			children();
	}
}

// makes a true O module
// m = number of octahedra in one unit (i.e., Z)
// apex = direction of polyhedral apex (0 = up, 1 = down)
module oModule(m = 2, apex = PLUS){  
	slideY(2*os, numBlocks -1)
		octZ(m, apex);
	if (numBlocks %1 ==0.5)
		#translate([0,2*os*(numBlocks-0.5),0])
		octZ(m, apex, oddsEvens=1);
}

// makes a true T-O-T module
module TOT(n=1,apex = PLUS,m=0){
	m = (m==0) ?  3*n-1 : m;
	TOTChild(n,apex,m){
		mirror([1,0,0])
		tModule(n);
		oModule(m,apex);
		tModule(n);
	}
}
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

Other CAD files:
stl/oblock/oblock-m11-minus.stl
stl/tblock/tblock-n4-plus.stl
3mf/connectors/chlorite-connector.3mf
3mf/oblock/oblock-m2-minus.3mf
3mf/connectors/mica-connector.3mf
3mf/oblock/oblock-m2-plus.3mf
3mf/oblock/oblock-m3-plus.3mf
3mf/oblock/oblock-m5-plus.3mf
3mf/oblock/oblock-m8-minus.3mf
3mf/oblock/oblock-m8-plus.3mf
3mf/oblock/single-octahedron-clips.3mf
3mf/oblock/single-octahedron.3mf
3mf/tblock/tblock-n1-minus.3mf
3mf/tblock/tblock-n2-plus.3mf
3mf/tblock/tblock-n3-minus.3mf
3mf/tblock/tblock-n3-plus.3mf
stl/connectors/brucite-connector.stl
stl/connectors/chlorite-connector.stl
stl/connectors/lizardite-connector.stl
stl/connectors/mica-connector.stl
stl/dual/tblock-n1-minus-dual-0.stl
stl/dual/tblock-n1-minus-dual-1.stl
stl/dual/tblock-n1-plus-dual-0.stl
stl/dual/tblock-n1-plus-dual-1.stl
stl/oblock/dioctahedral/oblock-dioctahedral-m11-minus.stl
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

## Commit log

2021-08-21 updated totblocks
    [totblocks.scad]
2021-12-22 added some echo statements
    [totblocks.scad]
2022-02-06 update the README.md with partial file structures
    [totblocks.scad]
2022-03-01 Added constants and parameters to README
    [totblocks.scad]
2022-03-02 Organized parameters for the Customizer in OpenSCAD and modified the readme accordingly
    [totblocks.scad]
2022-03-16 Added O block 3MF PrusaSlicer files
    [oblock-m2-plus.3mf, oblock-m5-plus.3mf, oblock-m8-plus.3mf]
2022-04-24 Added .3mf files
    [brucite-connector.3mf, chlorite-connector.3mf, lizardite-connector.3mf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]
2022-04-24 added bill of materials
2022-04-24 more bill of materials stuff
2022-05-19 rotated connectors sideways for printing purposes
    [brucite-connector.stl, chlorite-connector.stl, lizardite-connector.stl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]
2022-05-19 fixed prusaslicer files so that these print with supports and are flat lying
    [brucite-connector.3mf, chlorite-connector.3mf, lizardite-connector.3mf]
2023-03-11 Update totblocks.scad
    Added oBlockDioctahedral and oModuleDioctahedral methods, which allow for the production of dioctahedral O modules
    [totblocks.scad]
2023-03-11 Added stl files for dioctahedral O modules
    [oblock-dioctahedral-m11-minus.stl, oblock-dioctahedral-m11-plus.stl, oblock-dioctahedral-m5-minus.stl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]
2024-05-16 added smectite connector
    [smectite-connector.stl, totblocks.scad]
